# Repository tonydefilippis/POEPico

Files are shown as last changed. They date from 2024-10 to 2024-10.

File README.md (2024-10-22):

# POE Pico
"POE Pico" is a PCBA design for a RP2040 "Pi Pico" configured to support 40W active POE with Ethernet <-> USB conversion. 
# Diagram
Pre-print, the following 3D Views are available, but are not fully representative of the final product:
<br />Top<br />
<a href="https://ibb.co/r2JVWjt">3-Dview-Top</a>
<br />Bottom<br />
<a href="https://ibb.co/tpYNBwX">3-DView-Bot</a>

A PDF export of the schematic sheets for reference can be found [here](documentation/POEPico.pdf).
# Feature List
## Components
The USB to Ethernet conversion IC is a [LAN9500A](https://www.microchip.com/en-us/product/lan9500a). The board features a 40W active POE power/data supply input with a fully-isolated 12 VDC @ 2A Flyback courtesy of an [LT4295](https://www.analog.com/media/en/technical-documentation/data-sheets/LT4295.pdf). Downstream of the flyback is a 12V to 5V buck converter and 3.3V power rails. Ethernet magnetics and LEDs are fully integrated by the RJ45 connector. 

Alternatively, the board supports bringup of the RP2040 and power through the Micro-B connector. Powering the PCBA through the 5V Micro-B connector will also power the 3.3V rail. 
## Pins
Header pins expose standard RP2040 GPIO, including an isolated 12V, 5V, and 3.3V power rail.
| Purpose | Pin | Pin | Purpose | 
| --- | --- | --- | --- |
| GND | J21.1 | J21.2 | +3V3 |
| GND | J21.3 | J21.4 | GPIO0 |
| GND | J21.5 | J21.6 | GPIO1 |
| GND | J21.7 | J21.8 | GPIO2 |
| GND | J21.9 | J21.10 | GPIO3 |
| GND | J21.11 | J21.12 | GPIO4 |
| GND | J21.13 | J21.14 | GPIO5 |
| GND | J21.15 | J21.16 | GPIO6 |
| GND | J21.17 | J21.18 | GPIO7 |
| GND | J21.19 | J21.20 | GPIO8 |
| GND | J21.21 | J21.22 | GPIO9 |
| GND | J21.23 | J21.24 | GPIO10 |
| GND | J21.25 | J21.26 | GPIO11 |
| GND | J21.27 | J21.28 | GPIO12 |
| GND | J21.29 | J21.30 | GPIO13 |
| GND | J21.31 | J21.32 | GPIO14 |
| GND | J21.33 | J21.34 | GPIO15 |
| GND | J21.35 | J21.36 | +5V0 |

| Purpose | Pin | Pin | Purpose |
| --- | --- | --- | --- |
| SWCLK | J22.1 | J22.2 | GND |
| SWD | J22.3 | J22.4 | GND |
| RUN | J22.5 | J22.6 | GND |
| GPIO16 | J22.7 | J22.8 | GND |
| GPIO17 | J22.9 | J22.10 | GND |
| GPIO18 | J22.11 | J22.12 | GND |
| GPIO19 | J22.13 | J22.14 | GND |
| GPIO20 | J22.15 | J22.16 | GND |
| GPIO21 | J22.17 | J22.18 | GND |
| GPIO22 | J22.19 | J22.20 | GND |
| GPIO23 | J22.21 | J22.22 | GND |
| GPIO24 | J22.23 | J22.24 | GND |
| GPIO25 | J22.25 | J22.26 | GND |
| GPIO26 | J22.27 | J22.28 | GND |
| GPIO27 | J22.29 | J22.30 | GND |
| GPIO28 | J22.31 | J22.32 | GND |
| GPIO29 | J22.33 | J22.34 | GND |
| +12V0 | J22.35 | J22.26 | GND |

# Assembly
To be assembled as a 4-layer PCB, with associated BOM. Components to be placed on top and bottom of board. BOM has been edited to support JLCPCB quoting. Approximate cost estimate as of 21/10/2024 is $60/pc, including fabrication, components, assembly, and shipping.

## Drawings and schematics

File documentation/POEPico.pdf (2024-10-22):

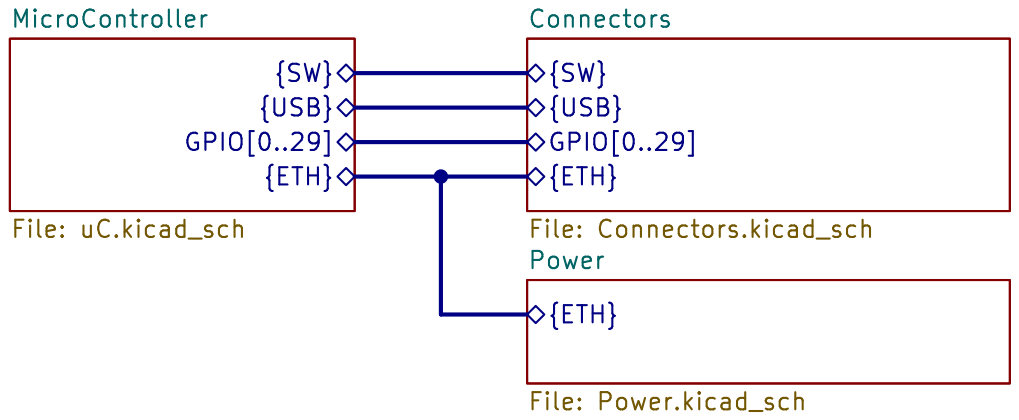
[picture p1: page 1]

{USB} MicroController File: uC.kicad_sch

GPIO[0..29] Connectors File: Connectors.kicad_sch

{ETH} Power File: Power.kicad_sch

Id: 1/4 Title: File: POEPico.kicad_sch Sheet: /

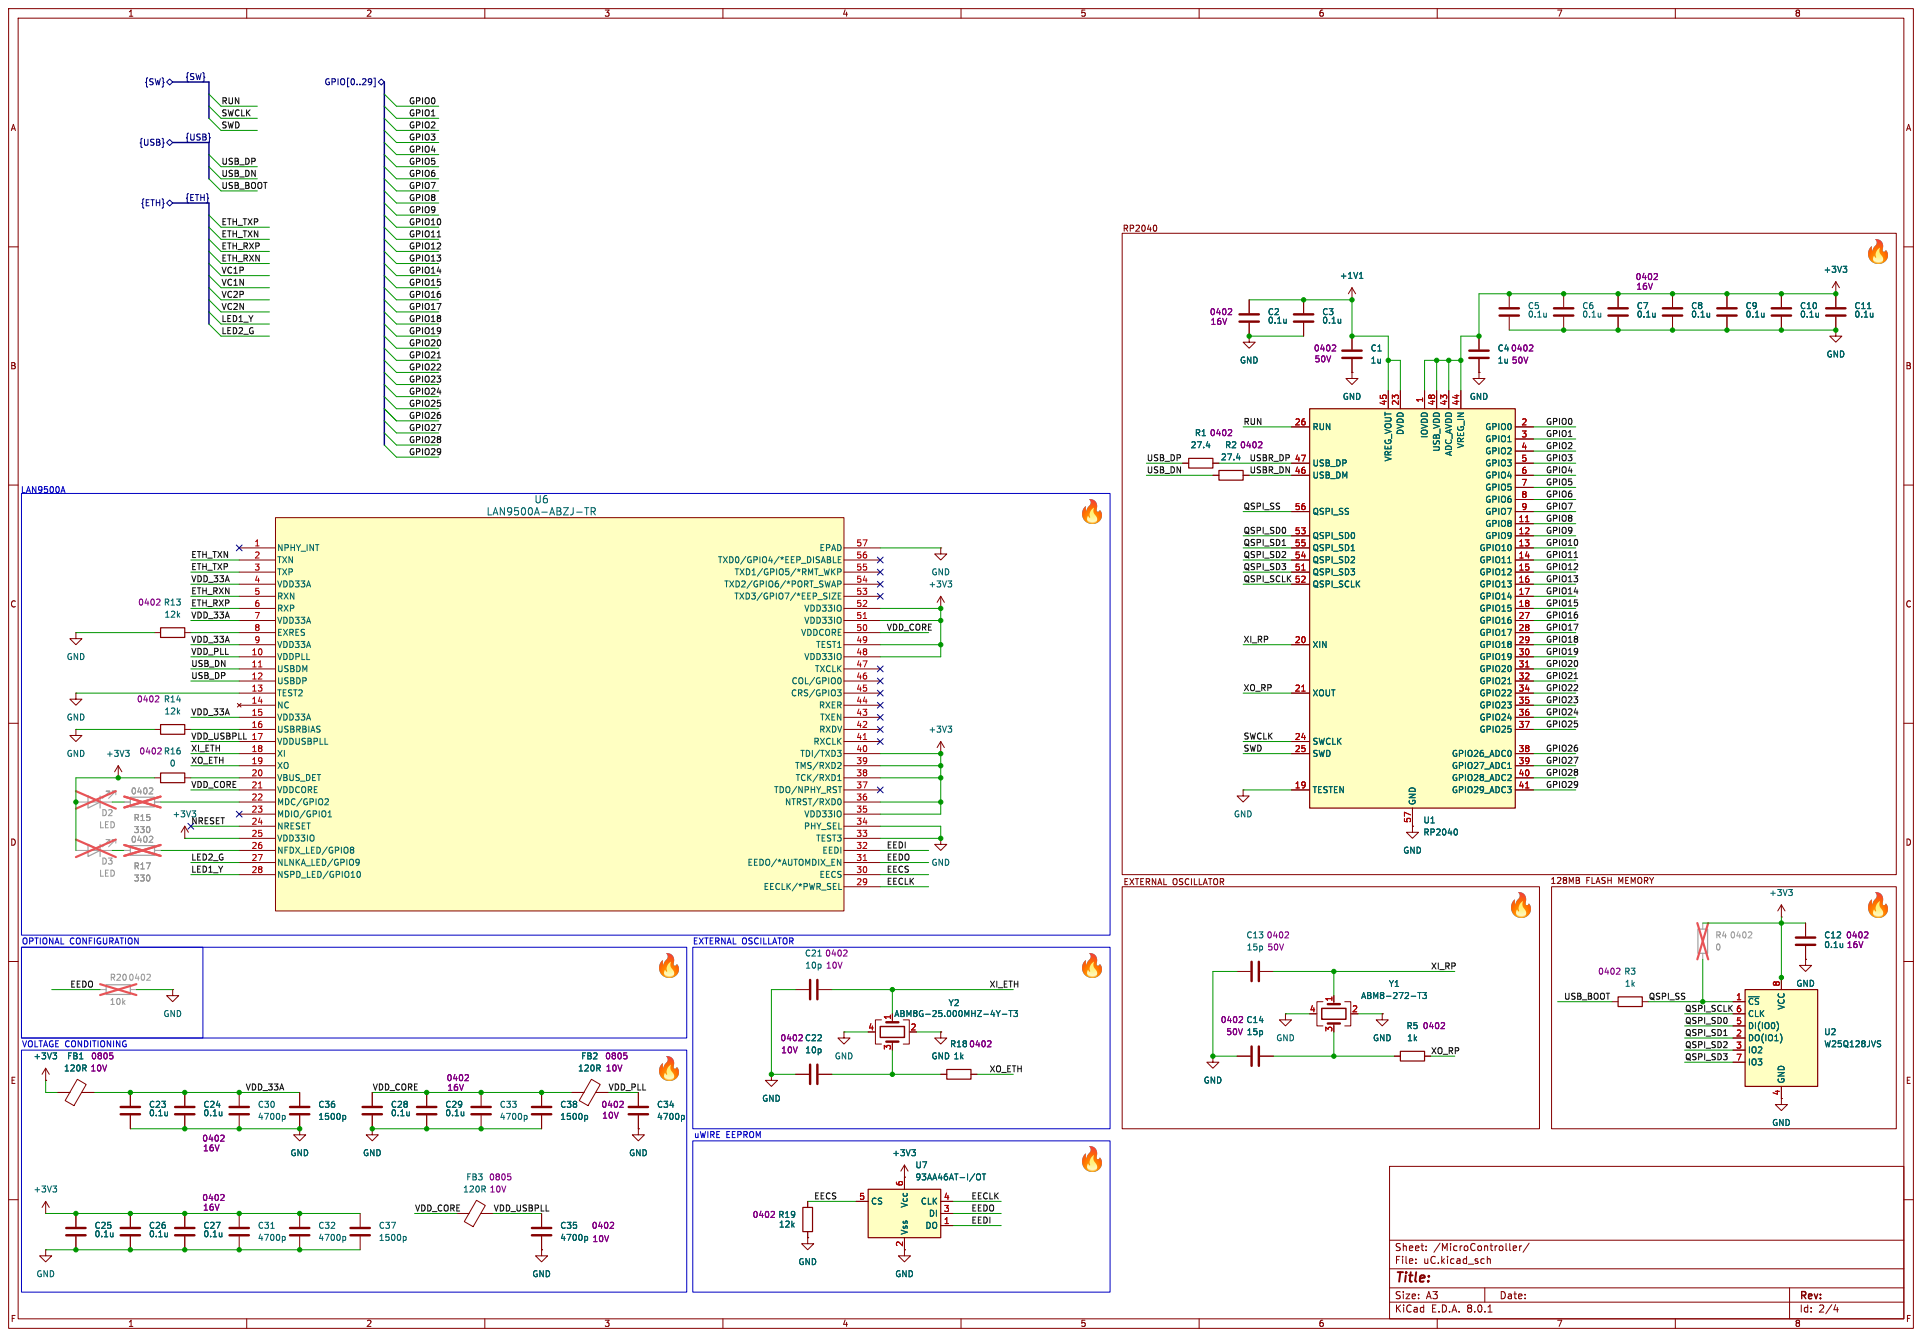
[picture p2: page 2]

1 GPIO8 11 GPIO9 12 GPIO10 13 GPIO11 14 GPIO12 15 GPIO13 16 GPIO14 17 GPIO15 18 TESTEN 19 GPIO0 2 XIN 20 XOUT 21 DVDD 23 SWCLK 24 SWD 25 RUN 26 GPIO16 27 GPIO17 28 GPIO18 29 GPIO1 3 GPIO19 30 GPIO20 31 GPIO21 32 GPIO22 34 GPIO23 35 GPIO24 36 GPIO25 37 GPIO26_ADC0 38 GPIO27_ADC1 39 GPIO2 4 GPIO28_ADC2 40 GPIO29_ADC3 41 ADC_AVDD 43 VREG_IN 44 VREG_VOUT 45 USB_DM 46 USB_DP 47 USB_VDD 48 GPIO3 5 QSPI_SD3 51 QSPI_SCLK 52 QSPI_SD0 53 QSPI_SD2 54 QSPI_SD1 55 QSPI_SS 56 GND 57 GPIO4 6 GPIO5 7 GPIO6 8 GPIO7 9 GND

1 GPIO8 11 GPIO9 12 GPIO10 13 GPIO11 14 GPIO12 15 GPIO13 16 GPIO14 17 GPIO15 18 TESTEN 19 GPIO0 2 XIN 20 XOUT 21 DVDD 23 SWCLK 24 SWD 25 RUN 26 GPIO16 27 GPIO17 28 GPIO18 29 GPIO1 3 GPIO19 30 GPIO20 31 GPIO21 32 GPIO22 34 GPIO23 35 GPIO24 36 GPIO25 37 GPIO26_ADC0 38 GPIO27_ADC1 39 GPIO2 4 GPIO28_ADC2 40 GPIO29_ADC3 41 ADC_AVDD 43 VREG_IN 44 VREG_VOUT 45 USB_DM 46 USB_DP 47 USB_VDD 48 GPIO3 5 QSPI_SD3 51 QSPI_SCLK 52 QSPI_SD0 53 QSPI_SD2 54 QSPI_SD1 55 QSPI_SS 56 GND 57 GPIO4 6 GPIO5 7 GPIO6 8 GPIO7 9 U1 RP2040 ~{CS} 1 DO(IO1) 2

Id: 2/4 Title: File: uC.kicad_sch Sheet: /MicroController/

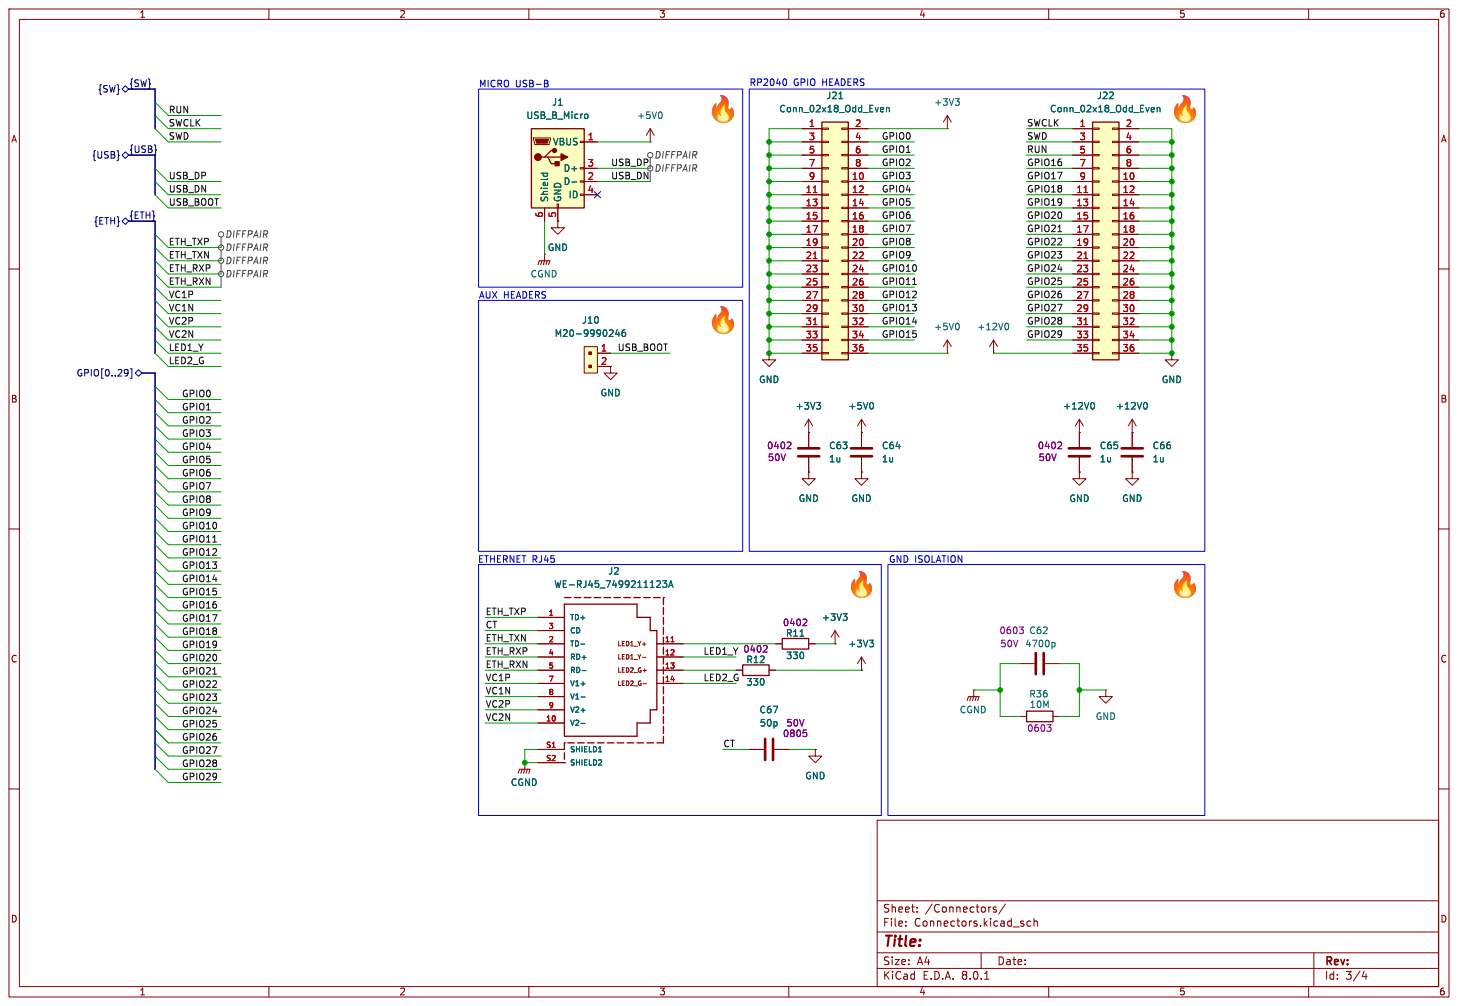
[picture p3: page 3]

Id: 3/4 Title: File: Connectors.kicad_sch Sheet: /Connectors/

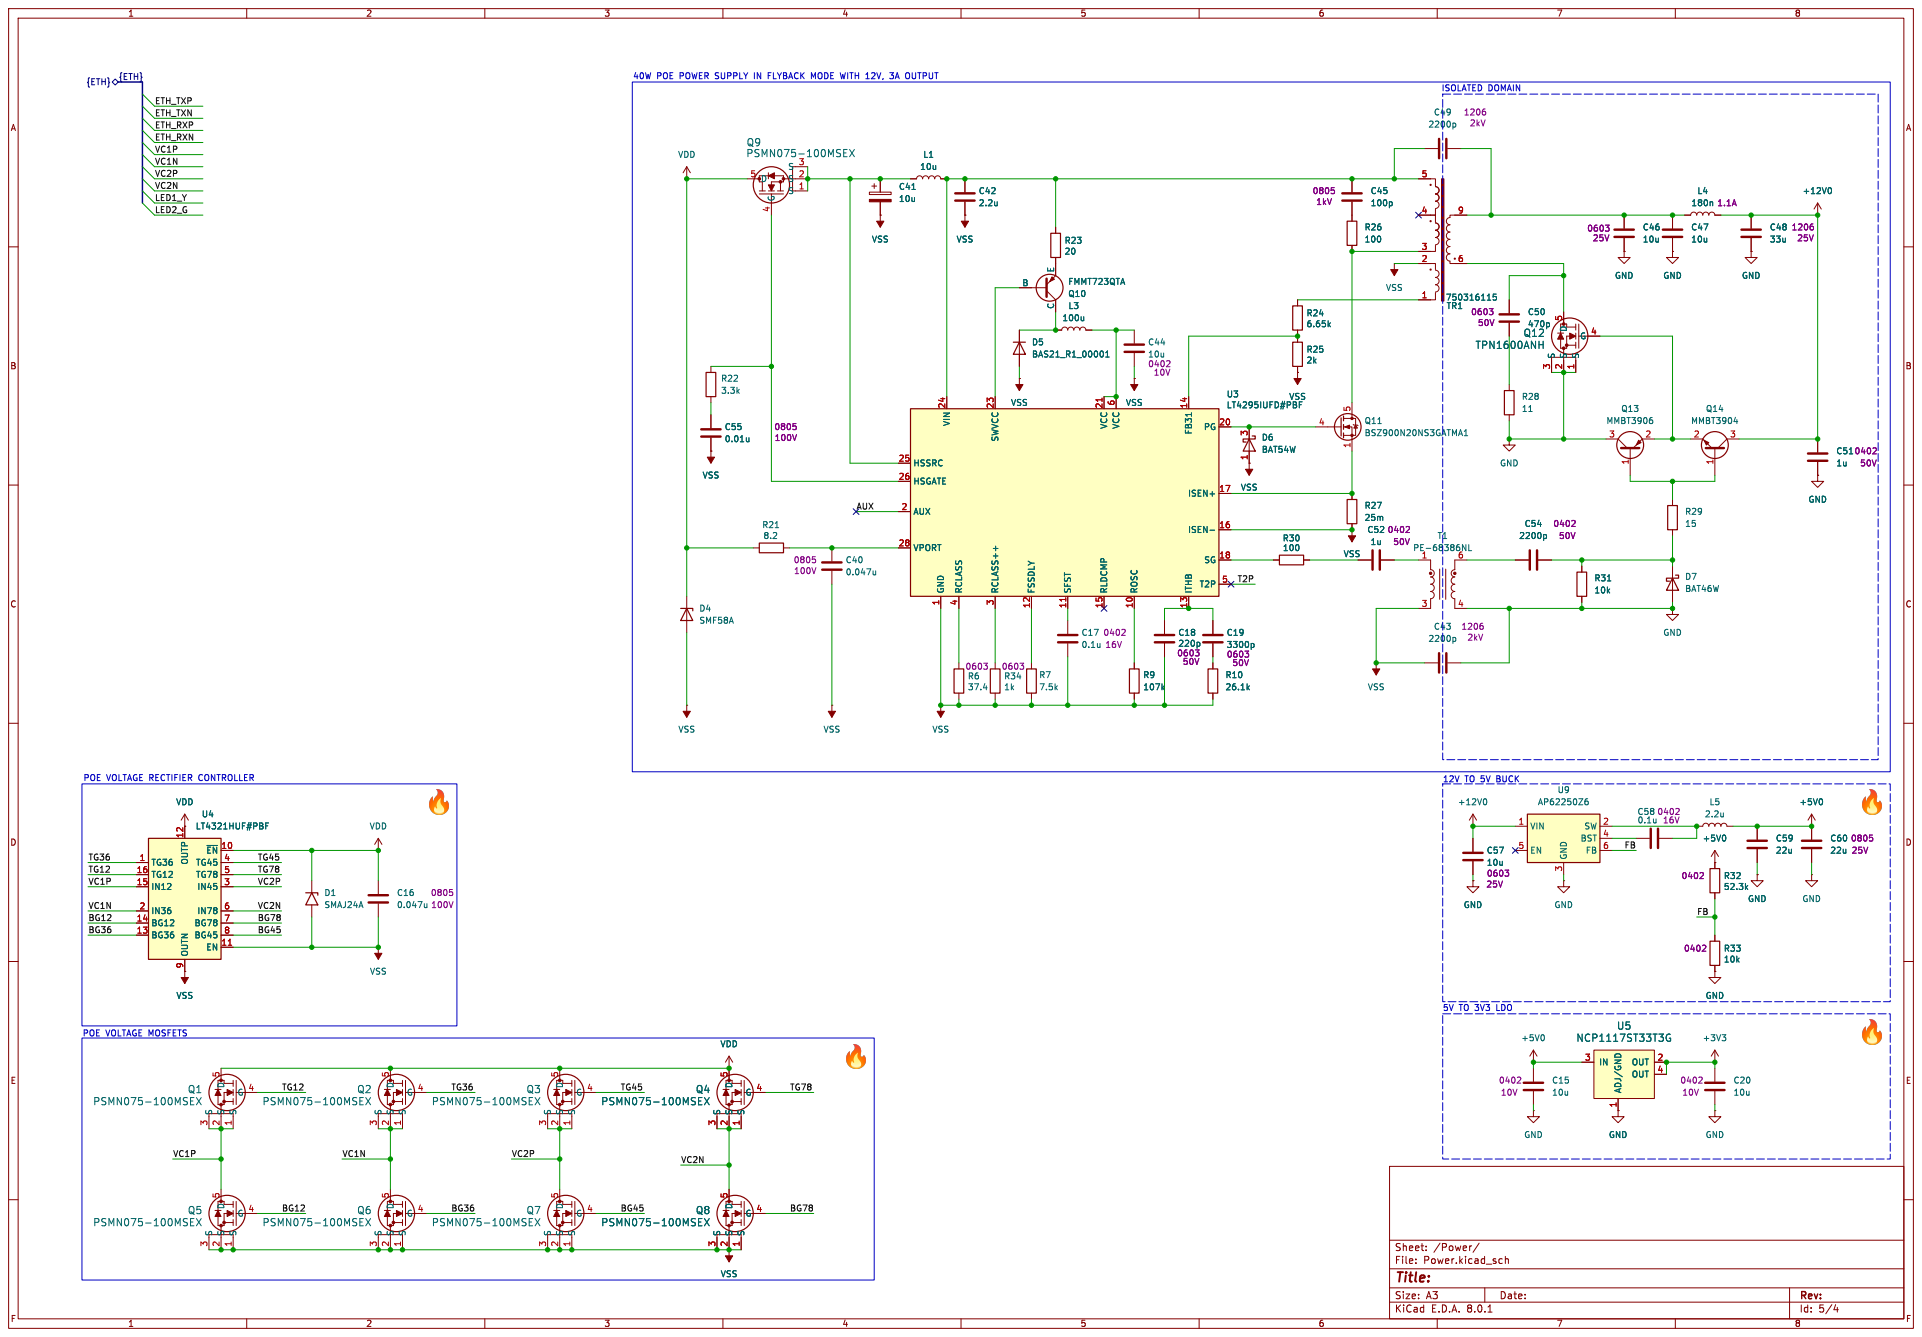
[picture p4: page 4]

40W POE POWER SUPPLY IN FLYBACK MODE WITH 12V, 3A OUTPUT

1 ROSC 10 SFST 11 FSSDLY 12 ITHB 13 FB31 14 RLDCMP 15
LT4295IUFD#PBF GND

POE VOLTAGE RECTIFIER CONTROLLER
VSS U4
LT4321HUF#PBF

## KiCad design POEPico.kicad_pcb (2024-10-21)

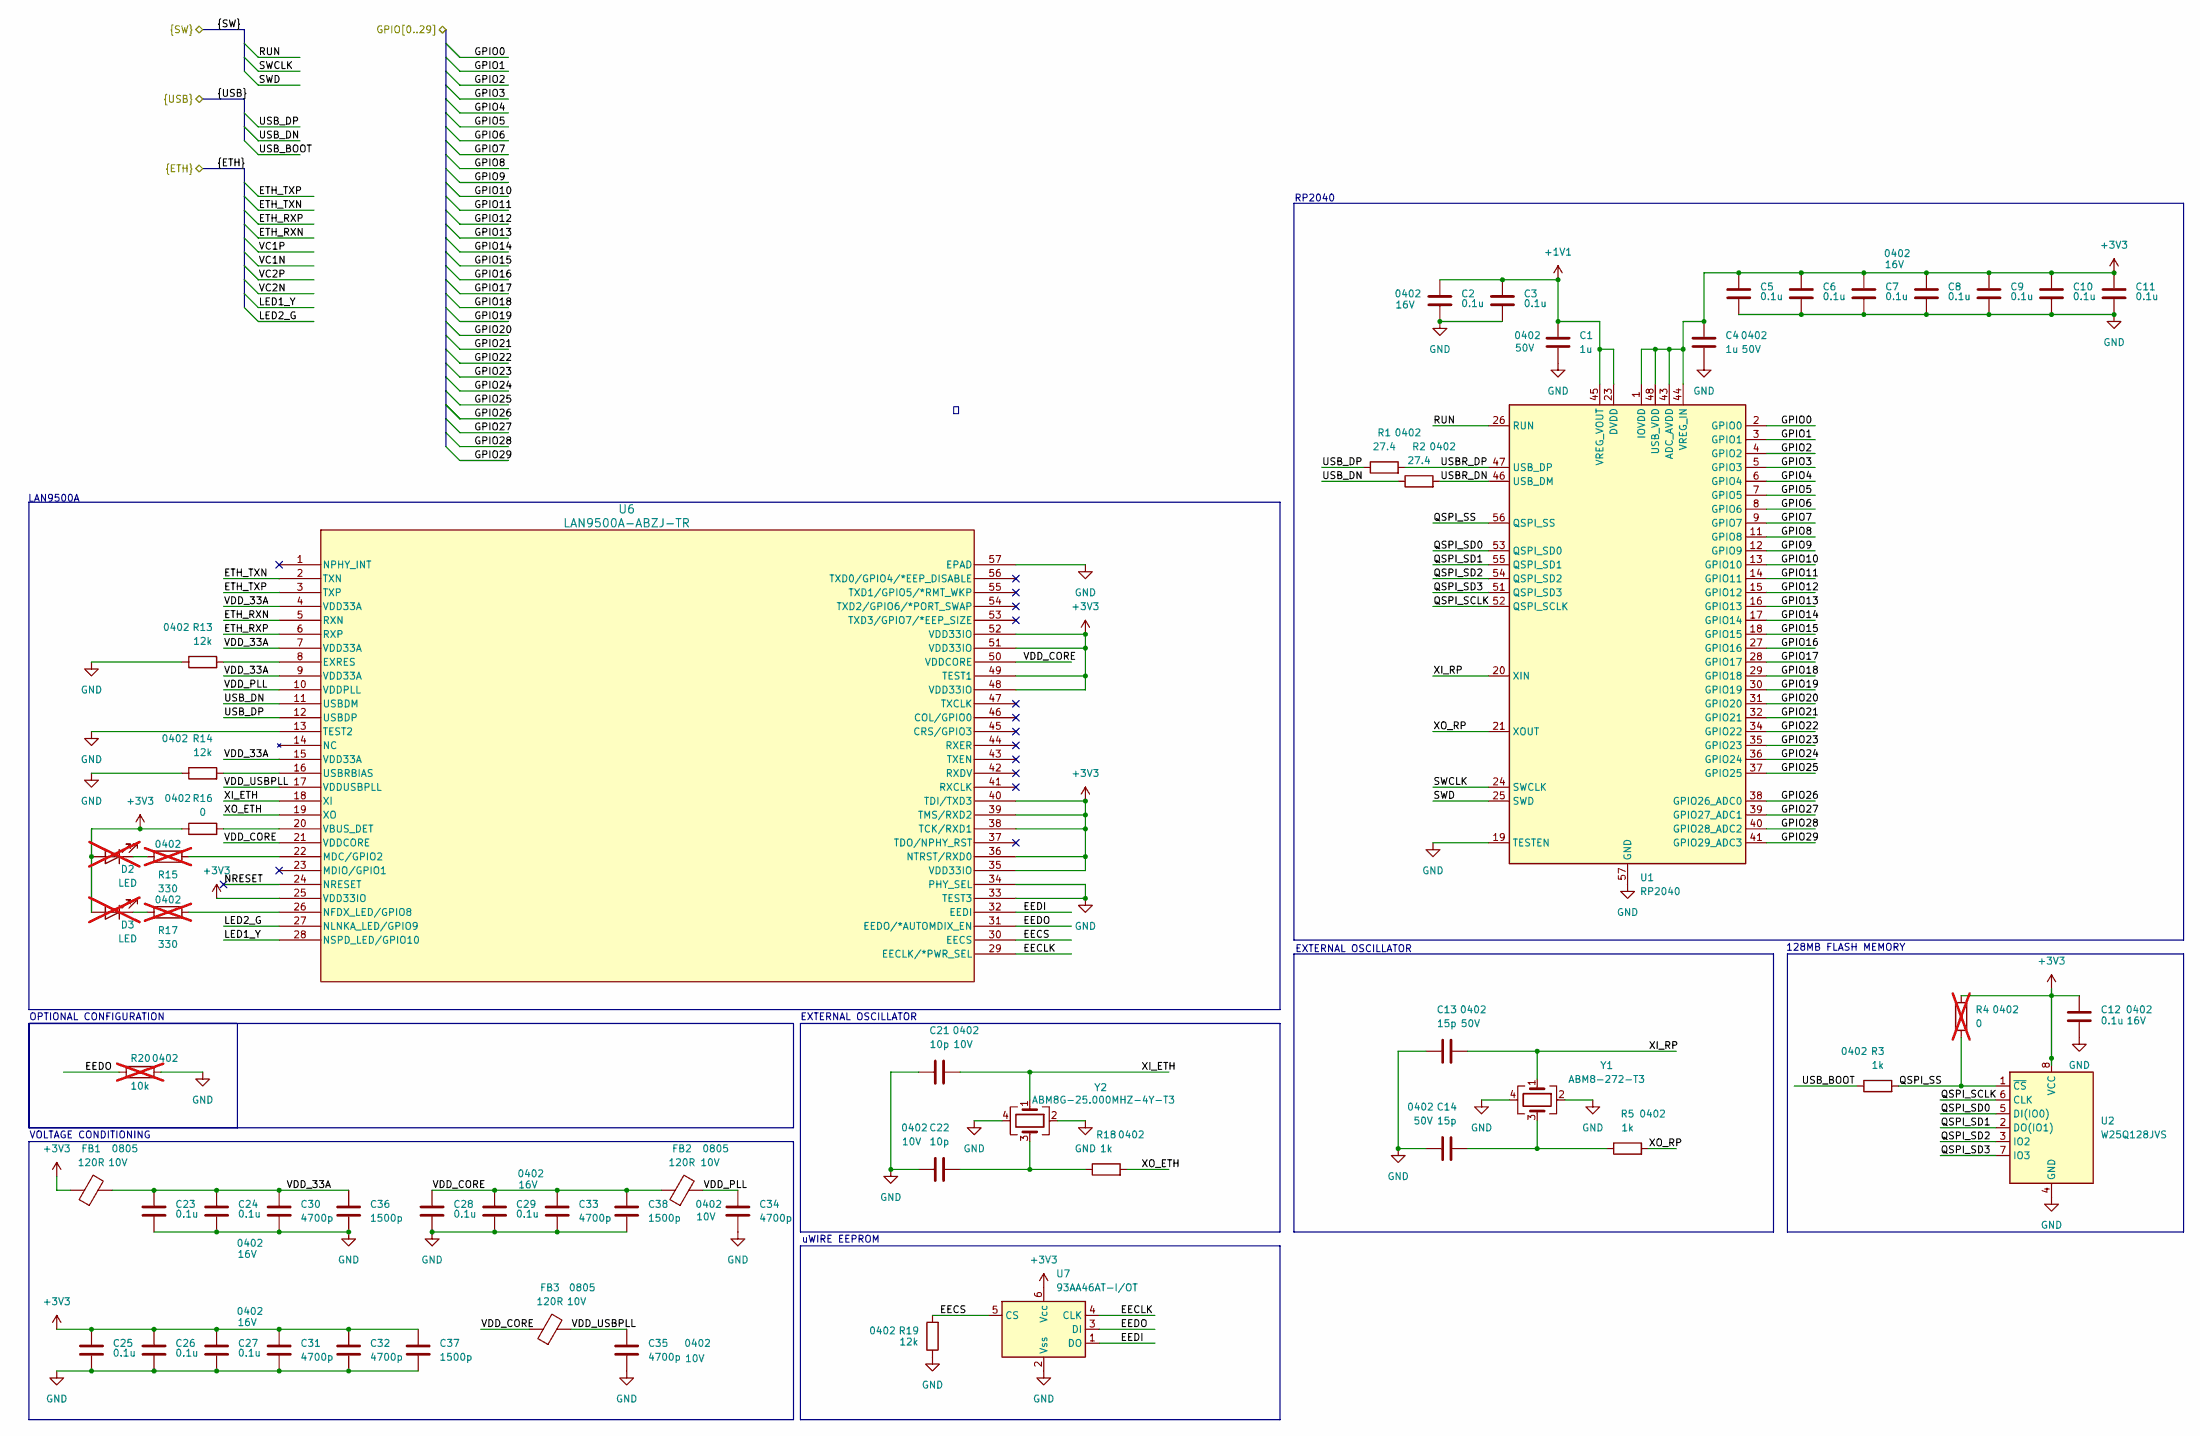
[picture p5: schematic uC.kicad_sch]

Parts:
C1, C4: 1u; C_0402_1005Metric; Rating 50V; PART-NUMBER C1518208
C2, C3, C5, C6, C7, C8, C9, C10, C11, C12, C23, C24, C25, C26, C27, C28, C29: 0.1u; C_0402_1005Metric; Rating 16V; PART-NUMBER C1525
C13, C14: 15p; C_0402_1005Metric; Rating 50V; PART-NUMBER C1548
C21, C22: 10p; C_0402_1005Metric; Rating 10V; PART-NUMBER C1545
C30, C31, C32, C33, C34, C35: 4700p; C_0402_1005Metric; Rating 10V; PART-NUMBER C7503510
C36, C37, C38: 1500p; C_0402_1005Metric; Rating 50V; PART-NUMBER C284989
D2, D3: LED; LED_0603; Rating 3.3V; not fitted
FB1, FB2, FB3: 120R; L_Eaton_MCL2012V1; Rating 10V; PART-NUMBER C88990
R1, R2: 27.4; R_0402_1005Metric; PART-NUMBER C284479
R3, R5, R18: 1k; R_0402_1005Metric; PART-NUMBER C106235
R4: 0; R_0402_1005Metric; PART-NUMBER C17168; not fitted
R13, R14, R19: 12k; R_0402_1005Metric; PART-NUMBER C102781
R15, R17: 330; R_0402_1005Metric; PART-NUMBER C25104; not fitted
R16: 0; R_0402_1005Metric; PART-NUMBER C17168
R20: 10k; R_0402_1005Metric; PART-NUMBER C60490; not fitted
U1: RP2040; QFN-56-1EP_7x7mm_P0.4mm_EP3.2x3.2mm; PART-NUMBER C2040
U2: W25Q128JVS; SOIC-8_5.23x5.23mm_P1.27mm; PART-NUMBER C97521
U6: LAN9500A-ABZJ-TR; QFN-56-1EP_8x8mm_P0.5mm_EP4.3x4.3mm; PART-NUMBER C2651877
U7: 93AA46AT-I/OT; SOT-23-6; PART-NUMBER C145736
Y1: ABM8-272-T3; 4-SMD_2.35x2.95mm; PART-NUMBER C20625731
Y2: ABM8G-25.000MHZ-4Y-T3; 4-SMD_2.35x2.95mm; PART-NUMBER C596914

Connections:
+1V1: C1.2, C2.1, C3.1, U1.23 (DVDD), U1.45 (VREG_VOUT), U1.50 (DVDD)
+3V3: C4.2, C5.1, C6.1, C7.1, C8.1, C9.1, C10.1, C11.1, C12.1, C25.1, C26.1, C27.1, C31.1, C32.1, C37.1, D2.2 (A), D3.2 (A), FB1.1, R4.1, R16.1, U1.1 (IOVDD), U1.10 (IOVDD), U1.22 (IOVDD), U1.33 (IOVDD), U1.42 (IOVDD), U1.43 (ADC_AVDD), U1.44 (VREG_IN), U1.48 (USB_VDD), U1.49 (IOVDD), U2.8 (VCC), U6.25 (VDD33IO), U6.35 (VDD33IO), U6.36 (NTRST/RXD0), U6.38 (TCK/RXD1), U6.39 (TMS/RXD2), U6.40 (TDI/TXD3), U6.48 (VDD33IO), U6.49 (TEST1), U6.51 (VDD33IO), U6.52 (VDD33IO), U7.6 (Vcc); also elsewhere on the board
/Connectors/ETH_RXN: U6.5 (RXN); also elsewhere on the board
/Connectors/ETH_RXP: U6.6 (RXP); also elsewhere on the board
/Connectors/ETH_TXN: U6.2 (TXN); also elsewhere on the board
/Connectors/ETH_TXP: U6.3 (TXP); also elsewhere on the board
/Connectors/GPIO0: U1.2 (GPIO0); also elsewhere on the board
/Connectors/GPIO1: U1.3 (GPIO1); also elsewhere on the board
/Connectors/GPIO2: U1.4 (GPIO2); also elsewhere on the board
/Connectors/GPIO3: U1.5 (GPIO3); also elsewhere on the board
/Connectors/GPIO4: U1.6 (GPIO4); also elsewhere on the board
/Connectors/GPIO5: U1.7 (GPIO5); also elsewhere on the board
/Connectors/GPIO6: U1.8 (GPIO6); also elsewhere on the board
/Connectors/GPIO7: U1.9 (GPIO7); also elsewhere on the board
/Connectors/GPIO8: U1.11 (GPIO8); also elsewhere on the board
/Connectors/GPIO9: U1.12 (GPIO9); also elsewhere on the board
/Connectors/GPIO10: U1.13 (GPIO10); also elsewhere on the board
/Connectors/GPIO11: U1.14 (GPIO11); also elsewhere on the board
/Connectors/GPIO12: U1.15 (GPIO12); also elsewhere on the board
/Connectors/GPIO13: U1.16 (GPIO13); also elsewhere on the board
/Connectors/GPIO14: U1.17 (GPIO14); also elsewhere on the board
/Connectors/GPIO15: U1.18 (GPIO15); also elsewhere on the board
/Connectors/GPIO16: U1.27 (GPIO16); also elsewhere on the board
/Connectors/GPIO17: U1.28 (GPIO17); also elsewhere on the board
/Connectors/GPIO18: U1.29 (GPIO18); also elsewhere on the board
/Connectors/GPIO19: U1.30 (GPIO19); also elsewhere on the board
/Connectors/GPIO20: U1.31 (GPIO20); also elsewhere on the board
/Connectors/GPIO21: U1.32 (GPIO21); also elsewhere on the board
/Connectors/GPIO22: U1.34 (GPIO22); also elsewhere on the board
/Connectors/GPIO23: U1.35 (GPIO23); also elsewhere on the board
/Connectors/GPIO24: U1.36 (GPIO24); also elsewhere on the board
/Connectors/GPIO25: U1.37 (GPIO25); also elsewhere on the board
/Connectors/GPIO26: U1.38 (GPIO26_ADC0); also elsewhere on the board
/Connectors/GPIO27: U1.39 (GPIO27_ADC1); also elsewhere on the board
/Connectors/GPIO28: U1.40 (GPIO28_ADC2); also elsewhere on the board
/Connectors/GPIO29: U1.41 (GPIO29_ADC3); also elsewhere on the board
/Connectors/LED1_Y: U6.28 (NSPD_LED/GPIO10); also elsewhere on the board
/Connectors/LED2_G: U6.27 (NLNKA_LED/GPIO9); also elsewhere on the board
/Connectors/RUN: U1.26 (RUN); also elsewhere on the board
/Connectors/SWCLK: U1.24 (SWCLK); also elsewhere on the board
/Connectors/SWD: U1.25 (SWD); also elsewhere on the board
/Connectors/USB_BOOT: R3.1; also elsewhere on the board
/Connectors/USB_DN: R2.1, U6.11 (USBDM); also elsewhere on the board
/Connectors/USB_DP: R1.1, U6.12 (USBDP); also elsewhere on the board
/MicroController/EECLK: U6.29 (EECLK/*PWR_SEL), U7.4 (CLK)
/MicroController/EECS: R19.2, U6.30 (EECS), U7.5 (CS)
/MicroController/EEDI: U6.32 (EEDI), U7.1 (DO)
/MicroController/EEDO: R20.1, U6.31 (EEDO/*AUTOMDIX_EN), U7.3 (DI)
/MicroController/NRESET: U6.24 (NRESET)
/MicroController/QSPI_SCLK: U1.52 (QSPI_SCLK), U2.6 (CLK)
/MicroController/QSPI_SD0: U1.53 (QSPI_SD0), U2.5 (DI(IO0))
/MicroController/QSPI_SD1: U1.55 (QSPI_SD1), U2.2 (DO(IO1))
/MicroController/QSPI_SD2: U1.54 (QSPI_SD2), U2.3 (IO2)
/MicroController/QSPI_SD3: U1.51 (QSPI_SD3), U2.7 (IO3)
/MicroController/QSPI_SS: R3.2, R4.2, U1.56 (QSPI_SS), U2.1 (~CS)
/MicroController/USBR_DN: R2.2, U1.46 (USB_DM)
/MicroController/USBR_DP: R1.2, U1.47 (USB_DP)
/MicroController/VDD_33A: C23.1, C24.1, C30.1, C36.1, FB1.2, U6.4 (VDD33A), U6.7 (VDD33A), U6.9 (VDD33A), U6.15 (VDD33A)
/MicroController/VDD_CORE: C28.1, C29.1, C33.1, C38.1, FB2.1, FB3.1, U6.21 (VDDCORE), U6.50 (VDDCORE)
/MicroController/VDD_PLL: C34.1, FB2.2, U6.10 (VDDPLL)
/MicroController/VDD_USBPLL: C35.1, FB3.2, U6.17 (VDDUSBPLL)
/MicroController/XI_ETH: C21.2, U6.18 (XI), Y2.1
/MicroController/XI_RP: C13.2, U1.20 (XIN), Y1.1
/MicroController/XO_ETH: R18.2, U6.19 (XO)
/MicroController/XO_RP: R5.2, U1.21 (XOUT)
GND: C1.1, C2.2, C3.2, C4.1, C5.2, C6.2, C7.2, C8.2, C9.2, C10.2, C11.2, C12.2, C13.1, C14.1, C21.1, C22.1, C23.2, C24.2, C25.2, C26.2, C27.2, C28.2, C29.2, C30.2, C31.2, C32.2, C33.2, C34.2, C35.2, C36.2, C37.2, C38.2, R13.1, R14.1, R19.1, R20.2, U1.19 (TESTEN), U1.57 (GND), U2.4 (GND), U6.13 (TEST2), U6.33 (TEST3), U6.34 (PHY_SEL), U6.57 (EPAD), U7.2 (Vss), Y1.2, Y1.4, Y2.2, Y2.4; also elsewhere on the board
unnamed: C14.2, R5.1, Y1.3
unnamed: C22.2, R18.1, Y2.3
unnamed: D2.1 (K), R15.1
unnamed: D3.1 (K), R17.1
unnamed: R13.2, U6.8 (EXRES)
unnamed: R15.2, U6.22 (MDC/GPIO2)
unnamed: R17.2, U6.26 (NFDX_LED/GPIO8)
unnamed: R14.2, U6.16 (USBRBIAS)
unnamed: R16.2, U6.20 (VBUS_DET)

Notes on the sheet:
EXTERNAL OSCILLATOR
LAN9500A
uWIRE EEPROM
OPTIONAL CONFIGURATION
RP2040
128MB FLASH MEMORY
VOLTAGE CONDITIONING

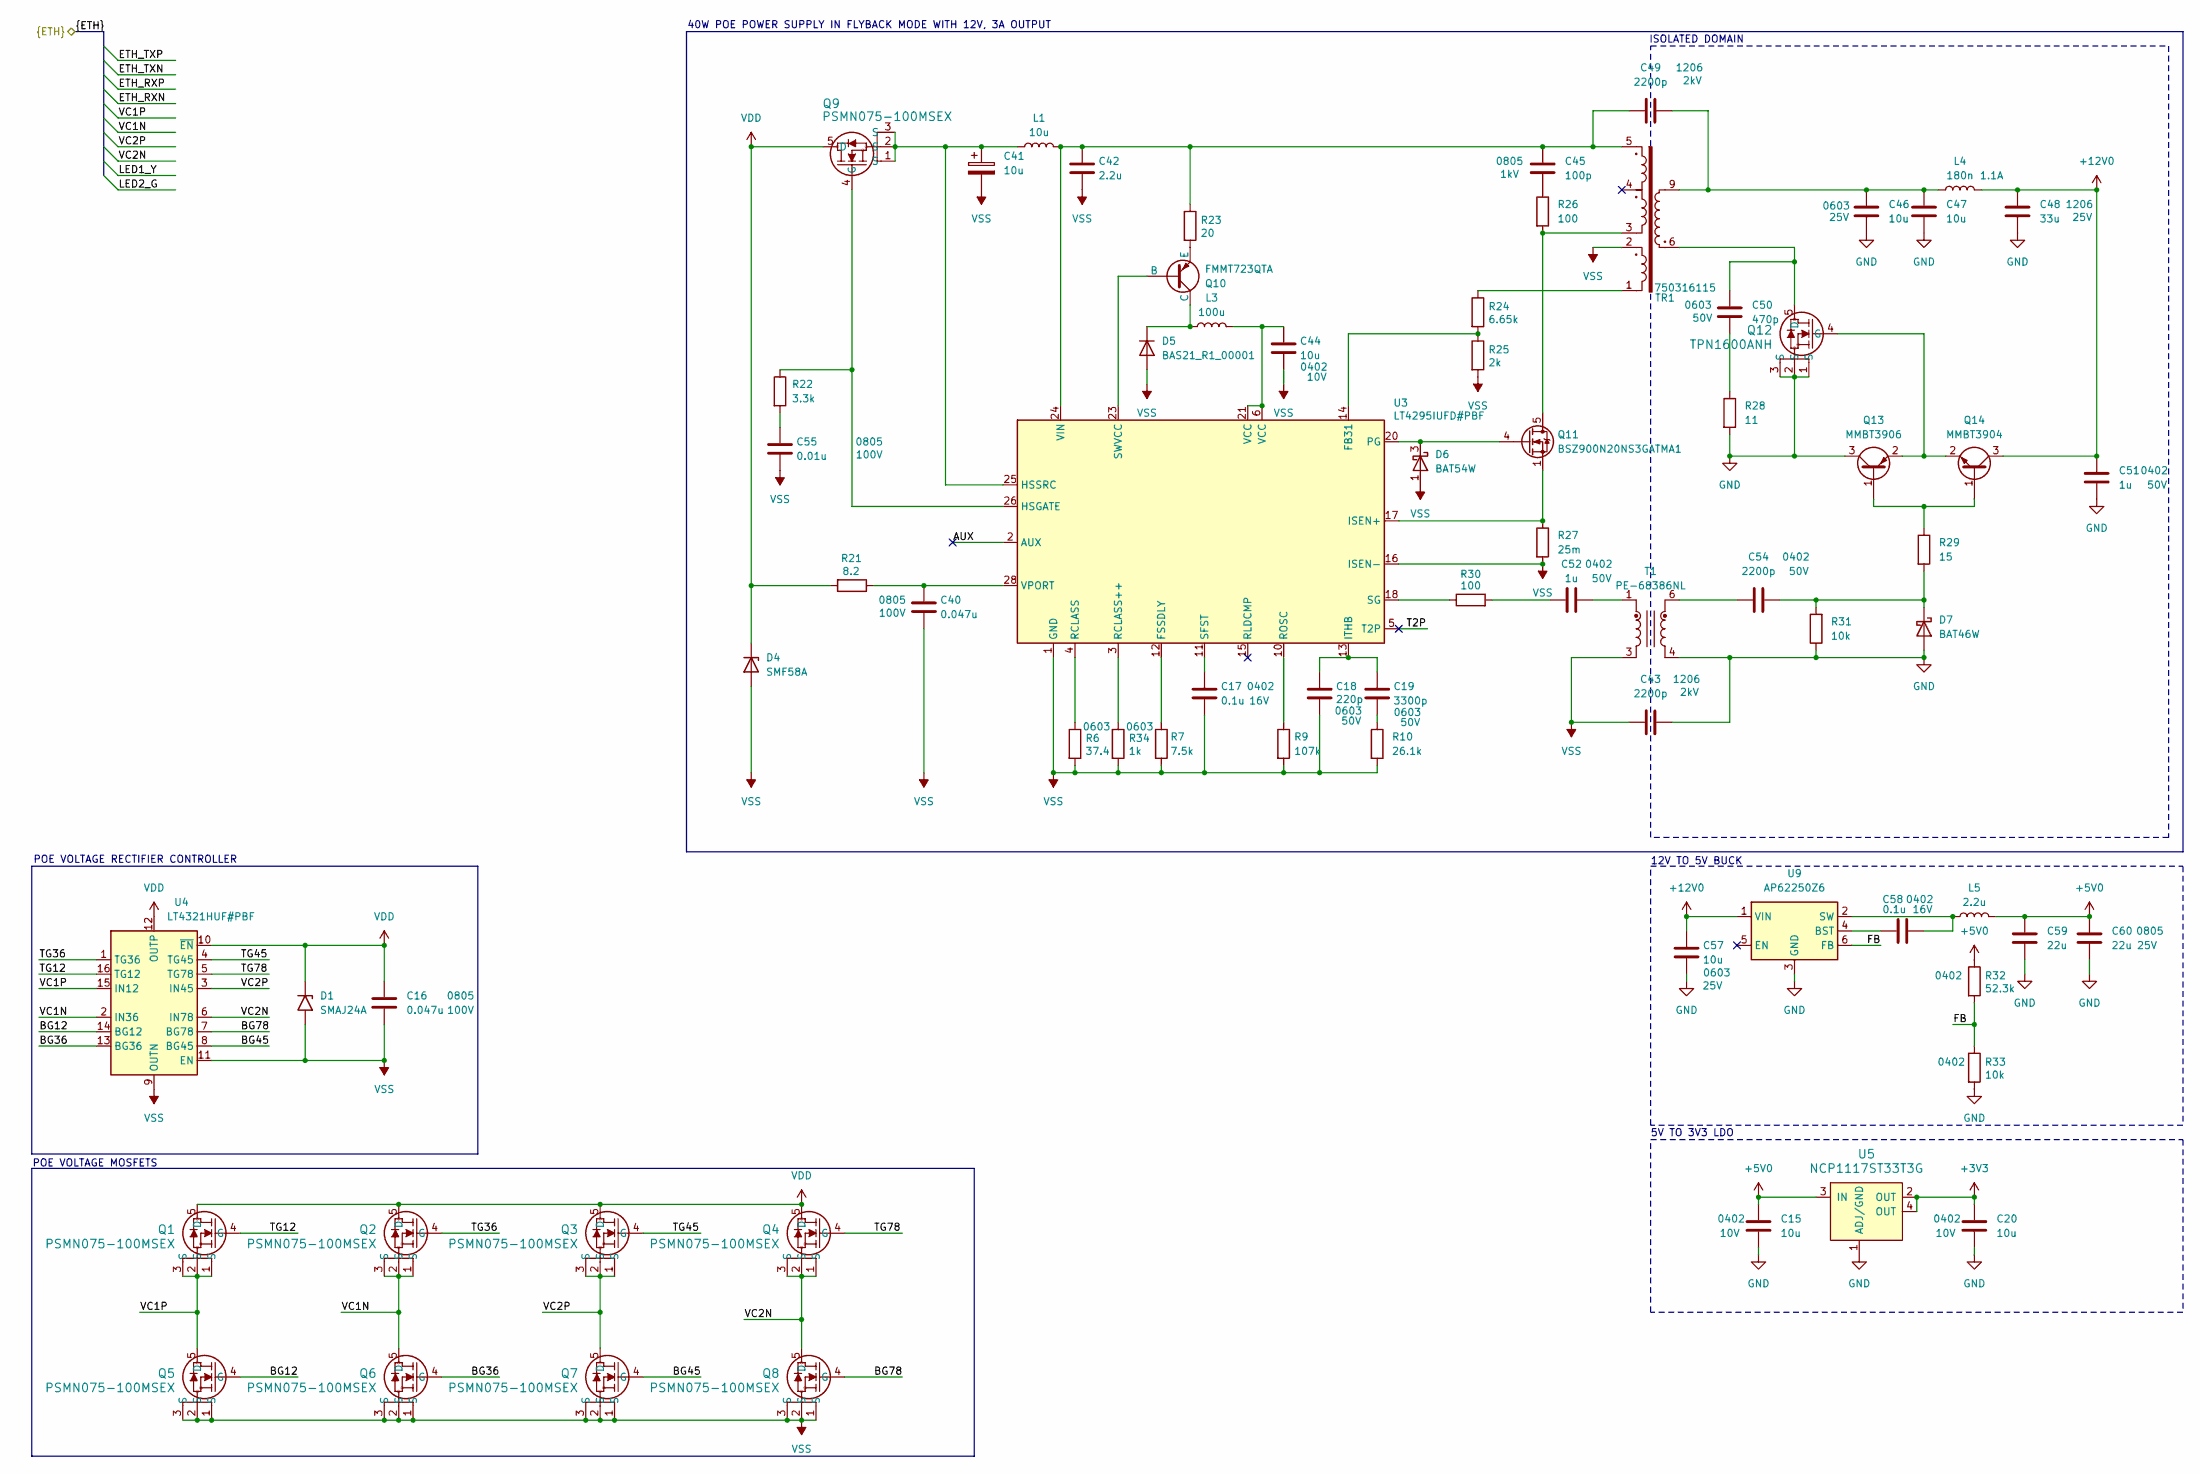
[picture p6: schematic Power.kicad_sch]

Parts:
C15, C20, C44: 10u; C_0402_1005Metric; Rating 10V; PART-NUMBER C77000
C16, C40: 0.047u; C_0805_2012Metric; Rating 100V; PART-NUMBER C5186810
C17, C58: 0.1u; C_0402_1005Metric; Rating 16V; PART-NUMBER C1525
C18: 220p; C_0603_1608Metric; Rating 50V; PART-NUMBER C2897613
C19: 3300p; C_0603_1608Metric; Rating 50V; PART-NUMBER C5182463
C41: 10u; C_1210_3225Metric; Rating 100V; PART-NUMBER C72482
C42: 2.2u; C_0805_2012Metric; Rating 100V; PART-NUMBER C6119935
C43, C49: 2200p; C_1206_3216Metric; Rating 2kV; PART-NUMBER C41018
C45: 100p; C_0805_2012Metric; Rating 1kV; PART-NUMBER C967584
C46, C47, C57: 10u; C_0603_1608Metric; Rating 25V; PART-NUMBER C96446
C48: 33u; C_1206_3216Metric; Rating 25V; PART-NUMBER C342307
C50: 470p; C_0603_1608Metric; Rating 50V; PART-NUMBER C1620
C51, C52: 1u; C_0402_1005Metric; Rating 50V; PART-NUMBER C1518208
C54: 2200p; C_0402_1005Metric; Rating 50V; PART-NUMBER C915853
C55: 0.01u; C_0805_2012Metric; Rating 100V; PART-NUMBER C7503490
C59, C60: 22u; C_0402_1005Metric; Rating 25V; PART-NUMBER C45783
D1: SMAJ24A; D_SMA; PART-NUMBER C10769
D4: SMF58A; D_SOD-123; PART-NUMBER C435457
D5: BAS21_R1_00001; TSOT-23; PART-NUMBER C391392
D6: BAT54W; SOT-323_SC-70; PART-NUMBER C5186013
D7: BAT46W; D_SOD-123; PART-NUMBER C5805641
L1: 10u; FCH5030-100M; PART-NUMBER C20415529
L3: 100u; AABG05A20M101; PART-NUMBER C5119206
L4: 180n; L_0603_1608Metric; Rating 1.1A; PART-NUMBER C251952
L5: 2.2u; L_Murata_DFE201610P; PART-NUMBER C337891
Q1, Q2, Q3, Q4, Q5, Q6, Q7, Q8, Q9: PSMN075-100MSEX; LFPAK33_SOT1210_NEX; PART-NUMBER C478016
Q10: FMMT723QTA; TSOT-23; PART-NUMBER C5249004
Q11: BSZ900N20NS3GATMA1; TDSON-8-1; PART-NUMBER C3279283
Q12: TPN1600ANH; TDSON-8-1; PART-NUMBER C24363903
Q13: MMBT3906; SOT-23; PART-NUMBER C7420354
Q14: MMBT3904; SOT-23; PART-NUMBER C7420353
R6: 37.4; R_0603_1608Metric; PART-NUMBER C25195
R7: 7.5k; R_0603_1608Metric; PART-NUMBER C23234
R9: 107k; R_0603_1608Metric; PART-NUMBER C14889
R10: 26.1k; R_0603_1608Metric; PART-NUMBER C23356
R21: 8.2; R_0603_1608Metric; PART-NUMBER C23247
R22: 3.3k; R_0603_1608Metric; PART-NUMBER C22978
R23: 20; R_0603_1608Metric; PART-NUMBER C22950
R24: 6.65k; R_0603_1608Metric; PART-NUMBER C3016441
R25: 2k; R_0603_1608Metric; PART-NUMBER C22975
R26: 100; R_0805_2012Metric; Rating 1/2W; PART-NUMBER C441975
R27: 25m; R_0805_2012Metric; Rating 1/4W; PART-NUMBER C2767472
R28: 11; R_1210_3225Metric; Rating 1/2W; PART-NUMBER C422425
R29: 15; R_0603_1608Metric; PART-NUMBER C22810
R30: 100; R_0603_1608Metric; PART-NUMBER C22775
R31, R33: 10k; R_0402_1005Metric; PART-NUMBER C60490
R32: 52.3k; R_0402_1005Metric; PART-NUMBER C26982
R34: 1k; R_0603_1608Metric; PART-NUMBER C21190
T1: PE-68386NL; Pulse_PA2001NL; PART-NUMBER C581397
TR1: 750316115; PART-NUMBER C24363903
U3: LT4295IUFD#PBF; QFN-28-1EP_4x5mm_P0.5mm_EP2.65x3.65mm; PART-NUMBER C672449
U4: LT4321HUF#PBF; QFN-16-1EP_4x4mm_P0.65mm_EP2.15x2.15mm; PART-NUMBER C672474
U5: NCP1117ST33T3G; SOT-223; PART-NUMBER C26537
U9: AP62250Z6; SOT-563; PART-NUMBER C5290220

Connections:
+3V3: C20.1, U5.2 (OUT), U5.4 (OUT); also elsewhere on the board
+5V0: C15.1, C59.1, C60.1, L5.2, R32.1, U5.3 (IN); also elsewhere on the board
+12V0: C48.1, C51.1, C57.1, L4.2, Q14.3 (C), U9.1 (VIN); also elsewhere on the board
/Connectors/VC1N: Q2.1 (S), Q2.2 (S), Q2.3 (S), Q6.5 (D), U4.2 (IN36); also elsewhere on the board
/Connectors/VC1P: Q1.1 (S), Q1.2 (S), Q1.3 (S), Q5.5 (D), U4.15 (IN12); also elsewhere on the board
/Connectors/VC2N: Q4.1 (S), Q4.2 (S), Q4.3 (S), Q8.5 (D), U4.6 (IN78); also elsewhere on the board
/Connectors/VC2P: Q3.1 (S), Q3.2 (S), Q3.3 (S), Q7.5 (D), U4.3 (IN45); also elsewhere on the board
/Power/AUX: U3.2 (AUX)
/Power/BG12: Q5.4 (G), U4.14 (BG12)
/Power/BG36: Q6.4 (G), U4.13 (BG36)
/Power/BG45: Q7.4 (G), U4.8 (BG45)
/Power/BG78: Q8.4 (G), U4.7 (BG78)
/Power/FB: R32.2, R33.1, U9.6 (FB)
/Power/T2P: U3.5 (T2P)
/Power/TG12: Q1.4 (G), U4.16 (TG12)
/Power/TG36: Q2.4 (G), U4.1 (TG36)
/Power/TG45: Q3.4 (G), U4.4 (TG45)
/Power/TG78: Q4.4 (G), U4.5 (TG78)
GND: C15.2, C20.2, C43.2, C46.2, C47.2, C48.2, C51.2, C57.2, C59.2, C60.2, D7.2 (A), Q12.1 (S), Q12.2 (S), Q12.3 (S), Q13.3 (C), R28.2, R31.1, R33.2, T1.4, U5.1 (ADJ/GND), U9.3 (GND); also elsewhere on the board
unnamed: C19.2, R10.1
unnamed: C44.1, L3.2, U3.6 (VCC), U3.7 (VCC), U3.8 (VCC), U3.9 (VCC), U3.21 (VCC)
unnamed: C45.2, R26.1
unnamed: C46.1, C47.1, C49.2, L4.1, TR1.9, TR1.10
unnamed: C50.2, R28.1
unnamed: C52.1, R30.2
unnamed: C52.2, T1.1
unnamed: C54.1, T1.6
unnamed: C55.1, R22.2
unnamed: D5.3 (K), L3.1, Q10.1 (C)
unnamed: D6.3 (K), Q11.4 (G), U3.20 (PG)
unnamed: C54.2, D7.1 (K), R29.2, R31.2
unnamed: Q9.4 (G), R22.1, U3.26 (HSGATE)
unnamed: Q10.2 (B), U3.23 (SWVCC)
unnamed: Q10.3 (E), R23.2
unnamed: Q11.5 (D), R26.2, TR1.3
unnamed: C50.1, Q12.5 (D), TR1.6, TR1.7
unnamed: Q12.4 (G), Q13.2 (E), Q14.2 (E)
unnamed: Q13.1 (B), Q14.1 (B), R29.1
unnamed: R24.1, TR1.1
unnamed: R24.2, R25.1, U3.14 (FB31)
unnamed: R7.1, U3.12 (FSSDLY)
unnamed: C41.1, L1.1, Q9.1 (S), Q9.2 (S), Q9.3 (S), U3.25 (HSSRC)
unnamed: Q11.1 (S), Q11.2 (S), Q11.3 (S), R27.1, U3.17 (ISEN+)
unnamed: C18.1, C19.1, U3.13 (ITHB)
unnamed: R6.1, U3.4 (RCLASS)
unnamed: R34.1, U3.3 (RCLASS++)
unnamed: R9.1, U3.10 (ROSC)
unnamed: C17.1, U3.11 (SFST)
unnamed: R30.1, U3.18 (SG)
unnamed: C42.1, C45.1, C49.1, L1.2, R23.1, TR1.5, U3.24 (VIN)
unnamed: C40.1, R21.1, U3.28 (VPORT)
unnamed: C58.1, U9.4 (BST)
unnamed: C58.2, L5.1, U9.2 (SW)
VDD: C16.1, D1.1 (A1), D4.1 (K), Q1.5 (D), Q2.5 (D), Q3.5 (D), Q4.5 (D), Q9.5 (D), R21.2, U4.10 (~EN), U4.12 (OUTP)
VSS: C16.2, C17.2, C18.2, C40.2, C41.2, C42.2, C43.1, C44.2, C55.2, D1.2 (A2), D4.2 (A), D5.1 (A), D6.1 (A), Q5.1 (S), Q5.2 (S), Q5.3 (S), Q6.1 (S), Q6.2 (S), Q6.3 (S), Q7.1 (S), Q7.2 (S), Q7.3 (S), Q8.1 (S), Q8.2 (S), Q8.3 (S), R6.2, R7.2, R9.2, R10.2, R25.2, R27.2, R34.2, T1.3, TR1.2, U3.1 (GND), U3.16 (ISEN-), U3.19 (GND), U3.29 (GND), U4.9 (OUTN), U4.11 (EN), U4.17 (OUTN)

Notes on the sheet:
5V TO 3V3 LDO
POE VOLTAGE RECTIFIER CONTROLLER
12V TO 5V BUCK
POE VOLTAGE MOSFETS
ISOLATED DOMAIN
40W POE POWER SUPPLY IN FLYBACK MODE WITH 12V, 3A OUTPUT

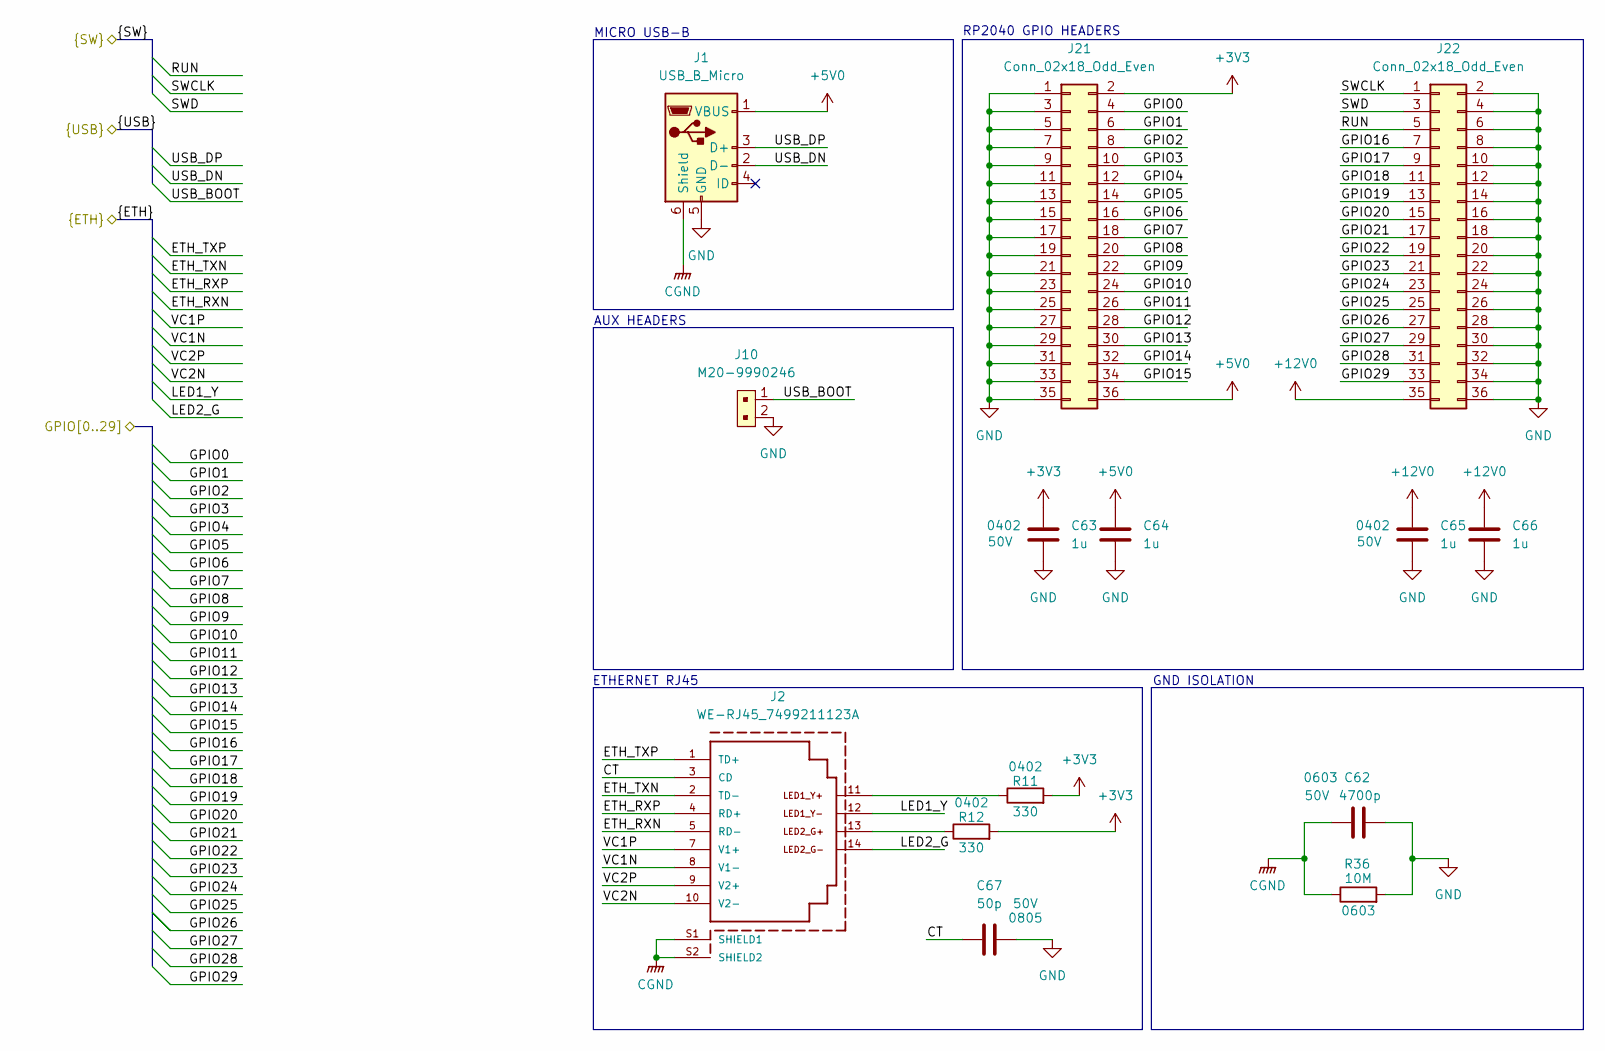
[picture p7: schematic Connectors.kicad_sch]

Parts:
C62: 4700p; C_0603_1608Metric; Rating 50V; PART-NUMBER C7503499
C63, C64, C65, C66: 1u; C_0402_1005Metric; Rating 50V; PART-NUMBER C1518208
C67: 50p; C_0805_2012Metric; Rating 50V; PART-NUMBER C1823
J1: USB_B_Micro; USB_Micro-B_Amphenol_10103594-0001LF_Horizontal; PART-NUMBER C428495
J2: WE-RJ45_7499211123A; 7499211123A; PART-NUMBER C24363903
J10: M20-9990246; PinHeader_1x2_P2.54mm; PART-NUMBER C706874
J21, J22: Conn_02x18_Odd_Even; PinHeader_2x18_P2.54mm_Vertical; PART-NUMBER C19184369
R11, R12: 330; R_0402_1005Metric; PART-NUMBER C25104
R36: 10M; R_0603_1608Metric; PART-NUMBER C7250

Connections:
+3V3: C63.2, J21.2, R11.2, R12.2; also elsewhere on the board
+5V0: C64.2, J1.1 (VBUS), J21.36; also elsewhere on the board
+12V0: C65.2, C66.2, J22.35; also elsewhere on the board
/Connectors/CT: C67.2, J2.3 (CD)
/Connectors/ETH_RXN: J2.5 (RD-); also elsewhere on the board
/Connectors/ETH_RXP: J2.4 (RD+); also elsewhere on the board
/Connectors/ETH_TXN: J2.2 (TD-); also elsewhere on the board
/Connectors/ETH_TXP: J2.1 (TD+); also elsewhere on the board
/Connectors/GPIO0: J21.4; also elsewhere on the board
/Connectors/GPIO1: J21.6; also elsewhere on the board
/Connectors/GPIO2: J21.8; also elsewhere on the board
/Connectors/GPIO3: J21.10; also elsewhere on the board
/Connectors/GPIO4: J21.12; also elsewhere on the board
/Connectors/GPIO5: J21.14; also elsewhere on the board
/Connectors/GPIO6: J21.16; also elsewhere on the board
/Connectors/GPIO7: J21.18; also elsewhere on the board
/Connectors/GPIO8: J21.20; also elsewhere on the board
/Connectors/GPIO9: J21.22; also elsewhere on the board
/Connectors/GPIO10: J21.24; also elsewhere on the board
/Connectors/GPIO11: J21.26; also elsewhere on the board
/Connectors/GPIO12: J21.28; also elsewhere on the board
/Connectors/GPIO13: J21.30; also elsewhere on the board
/Connectors/GPIO14: J21.32; also elsewhere on the board
/Connectors/GPIO15: J21.34; also elsewhere on the board
/Connectors/GPIO16: J22.7; also elsewhere on the board
/Connectors/GPIO17: J22.9; also elsewhere on the board
/Connectors/GPIO18: J22.11; also elsewhere on the board
/Connectors/GPIO19: J22.13; also elsewhere on the board
/Connectors/GPIO20: J22.15; also elsewhere on the board
/Connectors/GPIO21: J22.17; also elsewhere on the board
/Connectors/GPIO22: J22.19; also elsewhere on the board
/Connectors/GPIO23: J22.21; also elsewhere on the board
/Connectors/GPIO24: J22.23; also elsewhere on the board
/Connectors/GPIO25: J22.25; also elsewhere on the board
/Connectors/GPIO26: J22.27; also elsewhere on the board
/Connectors/GPIO27: J22.29; also elsewhere on the board
/Connectors/GPIO28: J22.31; also elsewhere on the board
/Connectors/GPIO29: J22.33; also elsewhere on the board
/Connectors/LED1_Y: J2.12; also elsewhere on the board
/Connectors/LED2_G: J2.14; also elsewhere on the board
/Connectors/RUN: J22.5; also elsewhere on the board
/Connectors/SWCLK: J22.1; also elsewhere on the board
/Connectors/SWD: J22.3; also elsewhere on the board
/Connectors/USB_BOOT: J10.1; also elsewhere on the board
/Connectors/USB_DN: J1.2 (D-); also elsewhere on the board
/Connectors/USB_DP: J1.3 (D+); also elsewhere on the board
/Connectors/VC1N: J2.8 (V1-); also elsewhere on the board
/Connectors/VC1P: J2.7 (V1+); also elsewhere on the board
/Connectors/VC2N: J2.10 (V2-); also elsewhere on the board
/Connectors/VC2P: J2.9 (V2+); also elsewhere on the board
CGND: C62.1, J1.6 (Shield), J2.S1 (SHIELD1), J2.S2 (SHIELD2), R36.1
GND: C62.2, C63.1, C64.1, C65.1, C66.1, C67.1, J1.5 (GND), J10.2, J21.1, J21.3, J21.5, J21.7, J21.9, J21.11, J21.13, J21.15, J21.17, J21.19, J21.21, J21.23, J21.25, J21.27, J21.29, J21.31, J21.33, J21.35, J22.2, J22.4, J22.6, J22.8, J22.10, J22.12, J22.14, J22.16, J22.18, J22.20, J22.22, J22.24, J22.26, J22.28, J22.30, J22.32, J22.34, J22.36, R36.2; also elsewhere on the board
unnamed: J2.11, R11.1
unnamed: J2.13, R12.1

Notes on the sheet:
GND ISOLATION
AUX HEADERS
MICRO USB-B
RP2040 GPIO HEADERS
ETHERNET RJ45

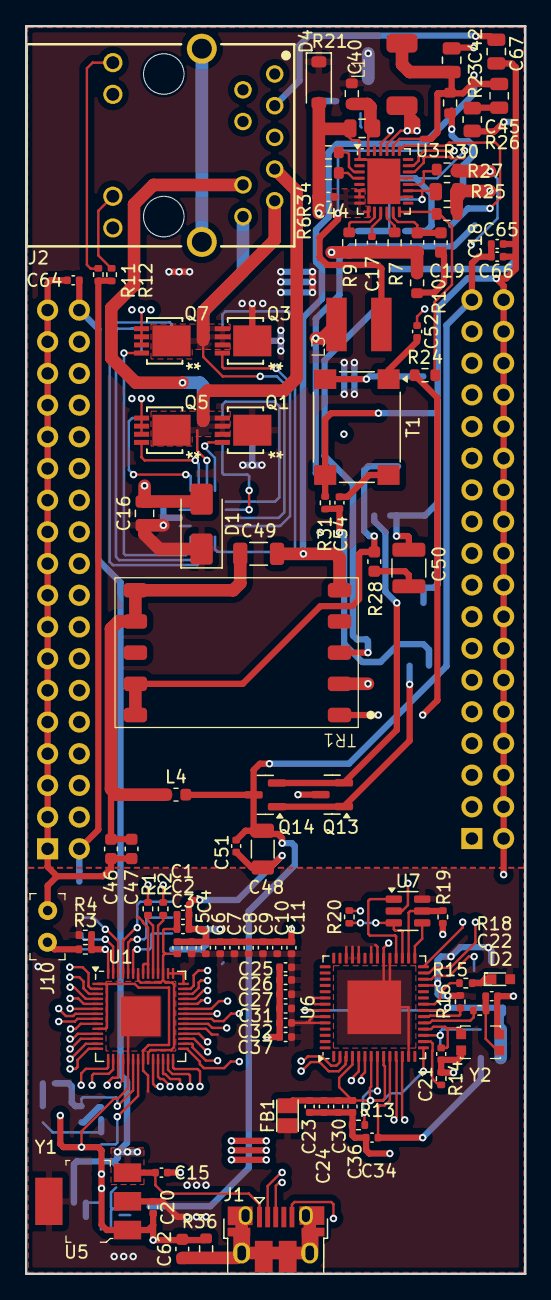
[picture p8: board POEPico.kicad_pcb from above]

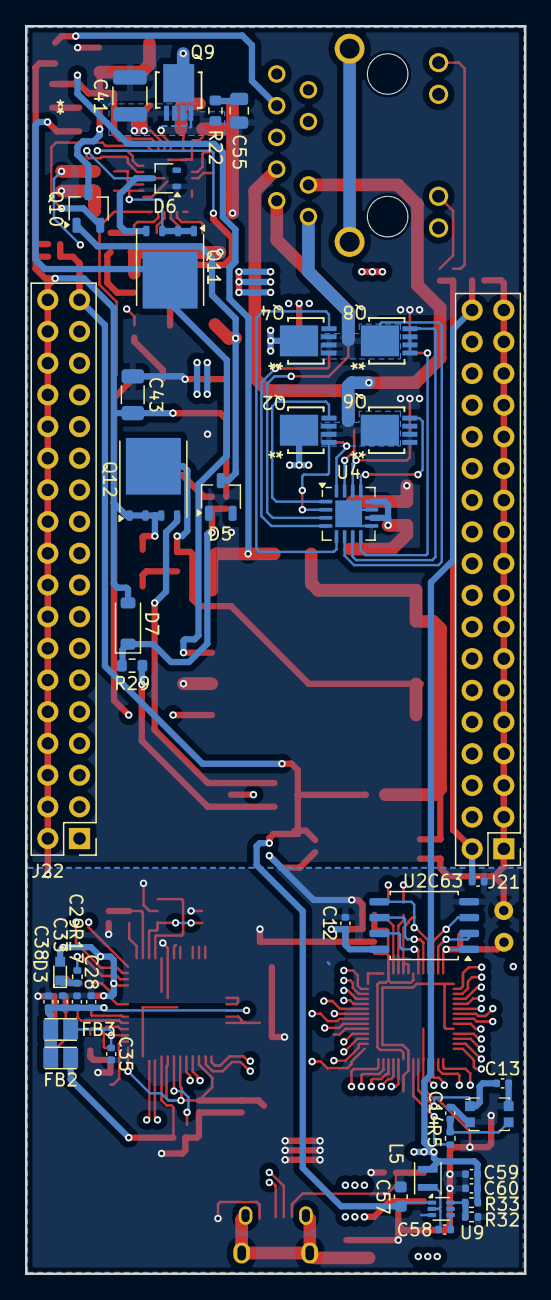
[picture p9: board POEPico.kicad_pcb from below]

Board: 4 copper layers, 40.0 x 100.0 mm, 142 parts (43 on the bottom side), 129 nets.

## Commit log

2024-10-11 Initial commit of project.
    [Connectors.,kicad_sch.kicad_sch, GPIO.kicad_sch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]
2024-10-21 BOM Cleanup and matching for JLCPCB, downstream edits to Schematic and Board. Added backup files to .gitignore.
    [Connectors.,kicad_sch.kicad_sch, Connectors.kicad_sch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]
2024-10-21 BOM Finalization, board cleanup.
    [Connectors.kicad_sch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]
2024-10-22 Adding exported PDF of schematics.
